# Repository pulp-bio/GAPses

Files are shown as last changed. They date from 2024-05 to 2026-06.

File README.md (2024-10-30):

# GAPses: 
## GAP9 based smart glasses for EEG and EOG acquisition and processing

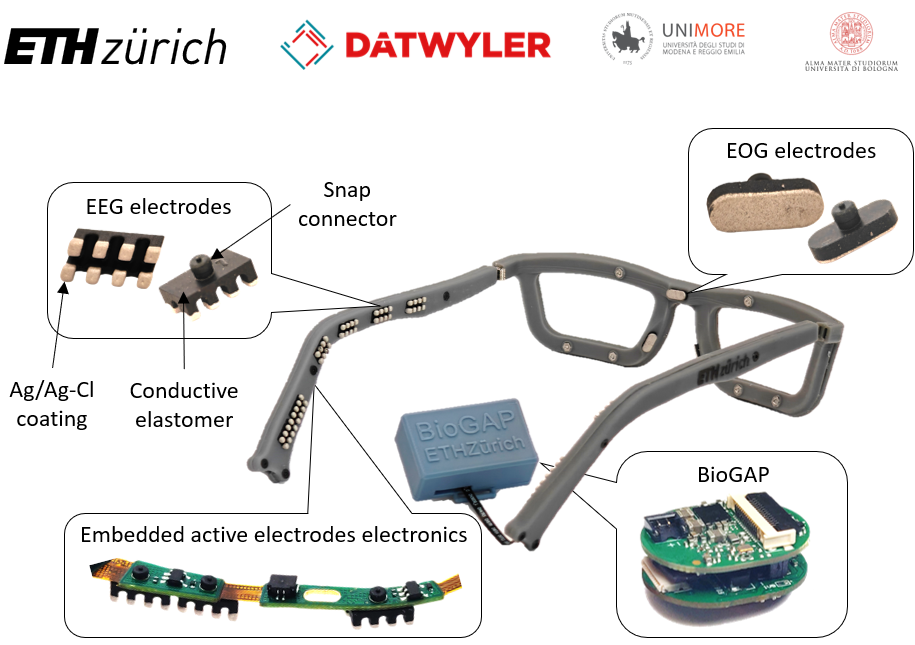
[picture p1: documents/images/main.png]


# Introduction

This repository contains the work in progress on the GAPses project.

GAPses are a pair of smart glasses for comfortable and fully dry acquisition and processing of EEG and EOG. The glasses are suitable for extended wear and various biopotential-based applications, including Human-Machine Interaction (HMI), biometric subject recognition, and real-time EEG/EOG analysis.

### Key Features
- **Lightweight & Comfortable**: The fully assembled glasses weigh only 40g and support unobtrusive, all-day wear.
- **Fully Dry Electrodes**: Custom soft electrodes provide stable contact without skin preparation.
- **Sleek Frame Design**: A sleek frame that discreetly houses electrodes and PCBs, ensuring a secure, comfortable fit for daily use.
- **Secure HMI Demonstration**: GAPses showcases a two-step Human-Machine Interaction (HMI) use case, where EEG-based biometric recognition (BrainMetrics) unlocks the device, followed by EOG-based HMI with a high information transfer rate.
- **End-to-End Edge Implementation**: The entire HMI use case, from BrainMetrics to EOG-based interactions, is processed on-device with GAP9’s ultra-low-power capabilities, enabling continuous, privacy-preserving operation on the edge.

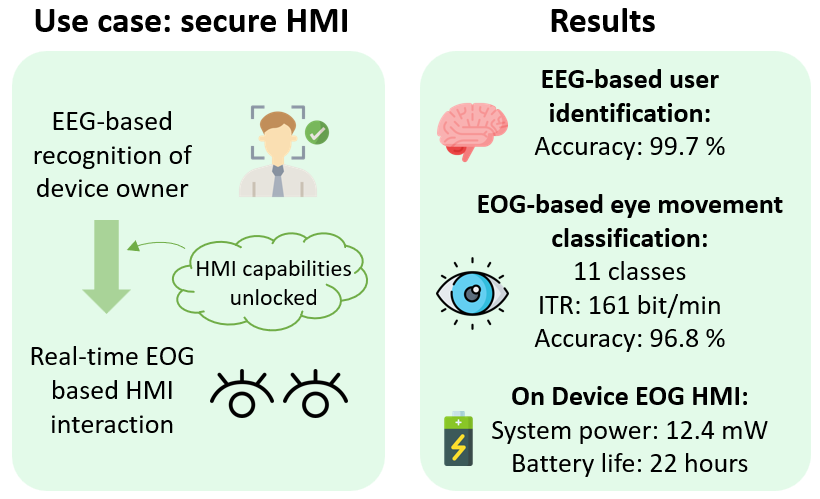
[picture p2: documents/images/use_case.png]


## System Diagram

The GAPses system comprises several key components:
- **BioGAP Acquisition and Processing Platform**: This platform enables real-time EEG and EOG data acquisition, processing, and classification on the edge with ultra-low power consumption using the GAP9 RISC-V processor.
- **Electrode Interface PCB**: A flex-rigid PCB embedded in the frame with active signal buffering stages and a direct PCB to electrode interface, reducing interference and artifacts.
- **Channel-Selection Interface PCB**: Allows users to switch between EEG-only and combined EEG-EOG configurations, optimizing channel selection for different use cases.

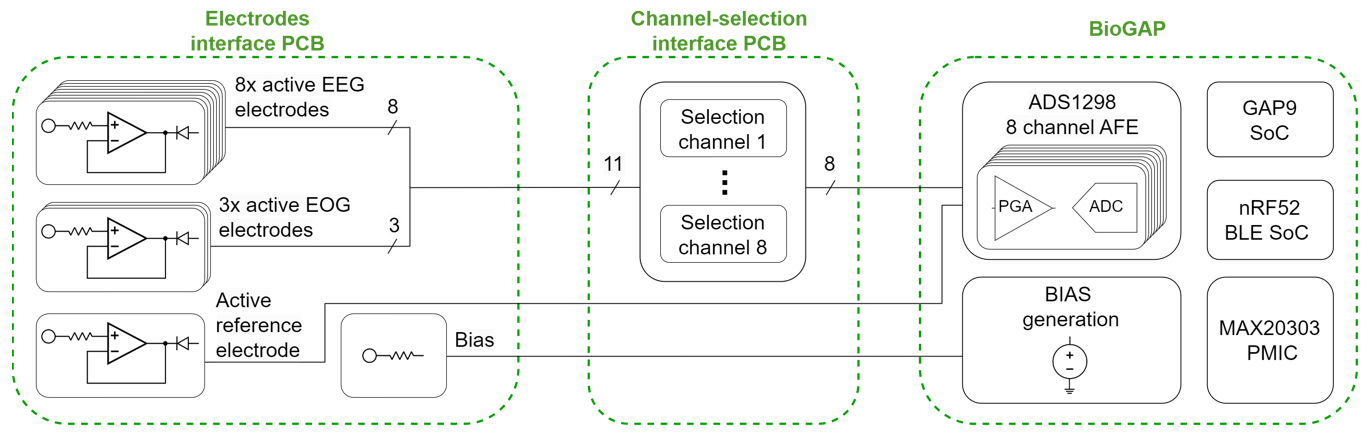
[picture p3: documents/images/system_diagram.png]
System Diagram


# Structure of the repository

This repository has the following folders:

- `hardware`, containing the Altium designer PCB source files and the frame design files 
    - Electrodes interface PCB (located at `hardware/PCBs/electrodes_interface_pcb`)
	- Breakout PCB (located at `hardware/PCBs/breakout_pcb`)
    - Frame files (located at `hardware/frame`)

- `documents`, containing the project documentation

# Citation
If you would like to reference the project, please cite the following paper:

```
@ARTICLE{frey2024gapses,
  author={Frey, Sebastian and Lucchini, Mattia Alberto and Kartsch, Victor and Ingolfsson, Thorir Mar and Bernardi, Andrea Helga and Segessenmann, Michael and Osieleniec, Jakub and Benatti, Simone and Benini, Luca and Cossettini, Andrea},
  journal={IEEE Transactions on Biomedical Circuits and Systems}, 
  title={GAPses: Versatile smart glasses for comfortable and fully-dry acquisition and parallel ultra-low-power processing of EEG and EOG}, 
  year={2024},
  volume={},
  number={},
  pages={1-11},
  keywords={Electroencephalography;Electrooculography;Electrodes;Glass;Smart glasses;Wireless communication;Biomedical monitoring;Wireless sensor networks;Sensors;Monitoring;BCI;EEG;embedded deployment;EOG;HMI;smart glasses;wearable devices},
  doi={10.1109/TBCAS.2024.3478798}}
```

# License

This project is open source. See the [LICENSE.README](./LICENSE.README.md) file for details.

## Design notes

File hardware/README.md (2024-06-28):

# Hardware files
This folder contains the following hardware design files:
 
- `PCBs`, containing the design files for the printed circuit boards (PCBs) of the GAPses project.
Each subdirectory corresponds to a separate PCB project. Inside you can find the Altium Nexus CAD design files and documentation in the `documents` folder.

- `frame`, containing the frame step files of the GAPses project.

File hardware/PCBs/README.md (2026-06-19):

# GAPses PCB design files
This directory contains the design files for selected printed circuit boards (PCBs) of the GAPses project.
Each subdirectory corresponds to a separate PCB project. Inside you can find the complete Altium Nexus CAD design files. To ease reproducability, gerber and NC drill files, schematics, bill of materials, assembly drawing and stackup regions are located in the `documents` folder of the respective PCB directory.

# License
The PCB design files are licensed under Solderpad v0.51 (`SHL-0.51`) license. Please, check the [hardware/PCBs/LICENSE](./LICENSE) file for details.

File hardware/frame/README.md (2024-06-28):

# GAPses frame design files

# License
The frame design files are licensed under the Solderpad v0.51 (`SHL-0.51`) license. Please, check the [hardware/frame/LICENSE](./LICENSE.md) file for details.

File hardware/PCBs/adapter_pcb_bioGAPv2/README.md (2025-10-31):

# BioGAP v2 Adapter PCB

The **BioGAP v2 Adapter PCB** facilitates the use of GAPses without the version 2 of the BioGAP acquisition platform.

## Features
- Enables the use of GAPses with BioGAP v2
- Supports EEG/EOG signal measurements

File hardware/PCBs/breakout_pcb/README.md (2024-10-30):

# Breakout PCB

The **Breakout PCB** facilitates the use of GAPses without the BioGAP acquisition platform. It provides access to all the signals on the electrode interface PCB, allowing other commercial or research biopotential acquisition platforms to be used in conjunction with GAPses.

## Features
- Enables the use of GAPses with non-BioGAP acquisition platforms
- Provides direct access to all electrode interface signals
- Supports EEG/EOG signal measurements
- Includes a DC offset of 2.048 V for proper operation of embedded electronics

## How to Connect the Breakout PCB

Follow these steps to connect the breakout PCB to your measurement system:

### 1. Powering the Breakout PCB
To power the breakout PCB, follow these steps:
   - Connect **GND** and **AVDD** to a lab power supply.
   - Set the power supply voltage to **3.0V (AVDD)**.

### 2. Measuring EEG/EOG Signals
Once powered, you can measure EEG and EOG signals by following these guidelines:
   - The signals are measured with respect to the **REF** pin (e.g., TL1 - REF, TL2 - REF, EOG L - REF, etc.).
   - The signals will have a **DC offset of 2.048 V**, which can be measured on the **BIAS** pin. This offset is necessary for the proper operation of the embedded electronics in the glasses frame and is generated by the breakout PCB.

### 3. Connecting to Measurement Device
   - Connect the channels you wish to measure to your measurement device. Ensure that the signals are correctly referenced with respect to the **REF** pin.

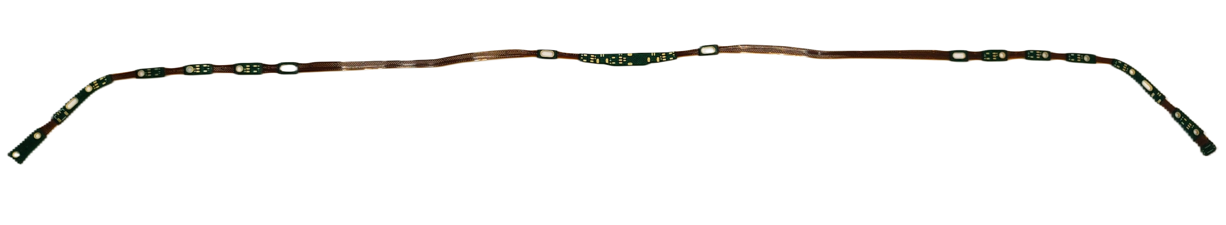
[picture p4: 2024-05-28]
documents/images/electrodes_interface_pcb.png

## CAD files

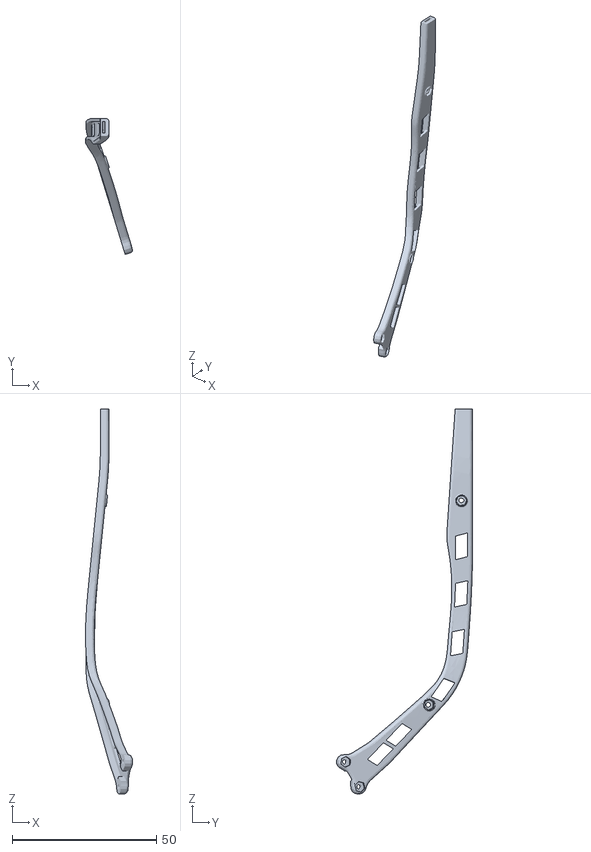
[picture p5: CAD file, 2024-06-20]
hardware/frame/ARM_RIGHT.stl
16.3 x 47.1 x 133.6

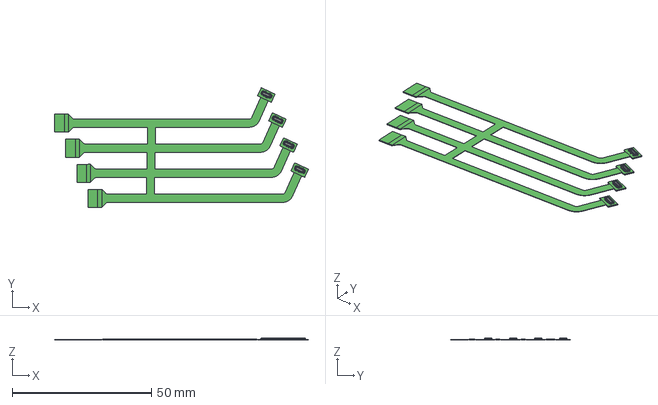
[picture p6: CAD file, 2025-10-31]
hardware/PCBs/adapter_pcb_bioGAPv2/flex_interface.step
91.3 x 43.0 x 0.845 mm

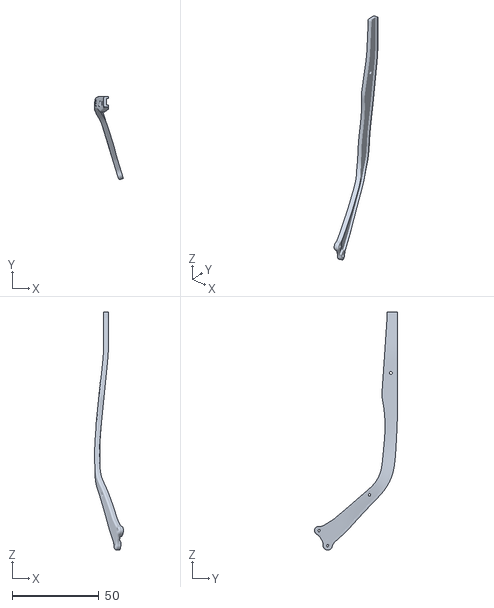
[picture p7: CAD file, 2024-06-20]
hardware/frame/LID_ETH.stl
16.6 x 47.8 x 137.1

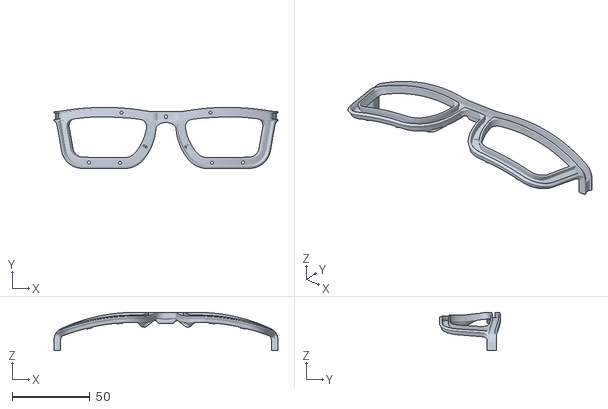
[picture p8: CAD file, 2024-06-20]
hardware/frame/FRONT_FRAME.stl
144.4 x 39.4 x 24.8

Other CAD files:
hardware/frame/ARM_LEFT.stl
hardware/frame/LID_Datwyler.stl

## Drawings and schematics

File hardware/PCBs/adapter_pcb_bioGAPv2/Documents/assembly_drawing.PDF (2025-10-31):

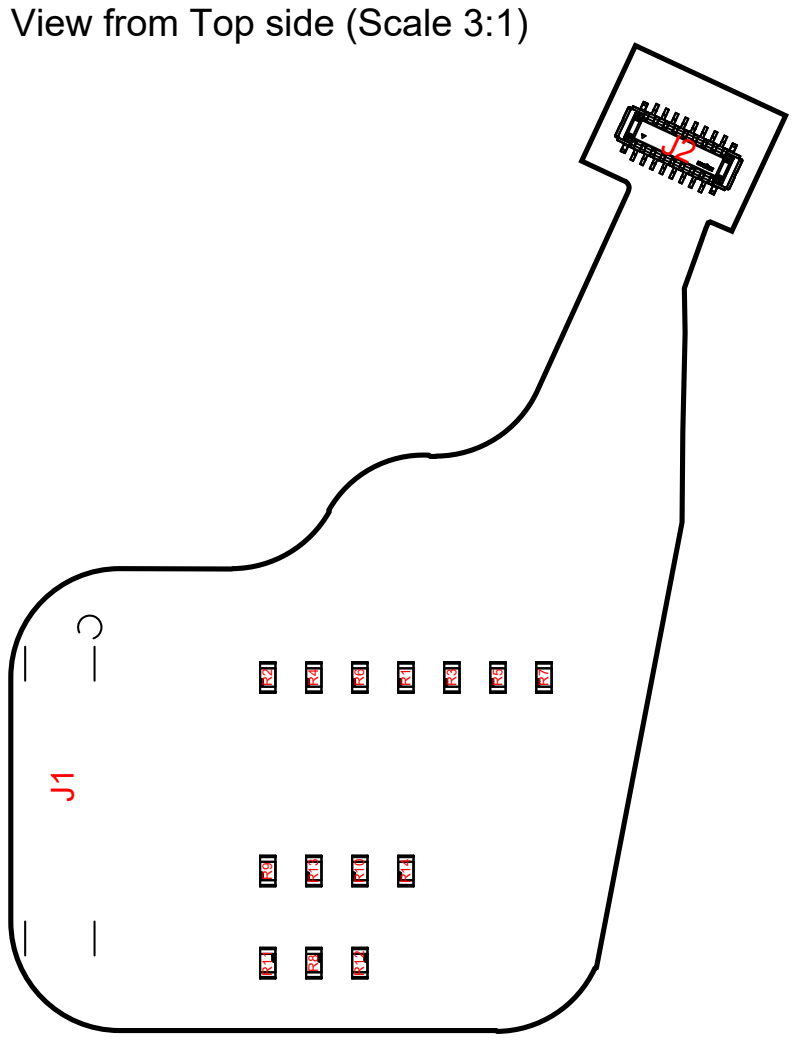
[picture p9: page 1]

View from Top side (Scale 3:1)

Drawing number:
Date:
C:\Users\s-fre\Github\GAPses\hardware\PCBs\adapter_pcb_bioGAPv2\ASSEMBLY.PCBDwf
File:

Laboratory: IIS ETH Zürich
Drawn by:

ASSEMBLY.PCBDwf
Sheet:
Page =sheetnumber of =sheettotal

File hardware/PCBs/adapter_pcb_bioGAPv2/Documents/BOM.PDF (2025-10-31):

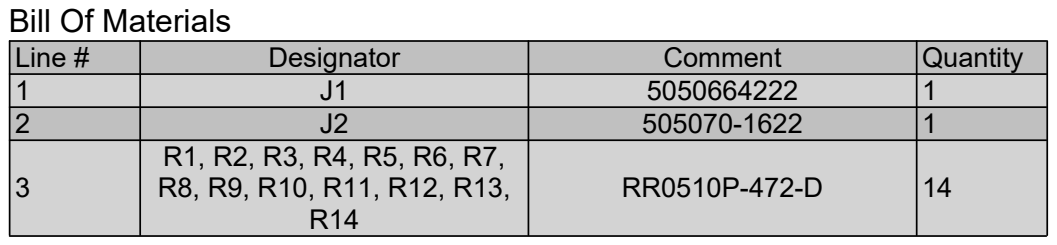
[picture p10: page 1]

Line # | Designator | Comment | Quantity
1 | J1 | 5050664222 | 1
2 | J2 | 505070-1622 | 1
3 | R1, R2, R3, R4, R5, R6, R7, R8, R9, R10, R11, R12, R13, R14 | RR0510P-472-D | 14

Project:

Drawing number: Rev: v1.0 Date: 07.07.2025 19:31 | Format: | Laboratory: IIS ETH Zürich Drawn by: S.Frey | Sheet: BOM.PCBDwf Page =sheetnumber of =sheettotal

C:\Users\s-fre\Github\GAPses\hardware\PCBs\adapter_pcb_bioGAPv2\BOM.PCBDwf

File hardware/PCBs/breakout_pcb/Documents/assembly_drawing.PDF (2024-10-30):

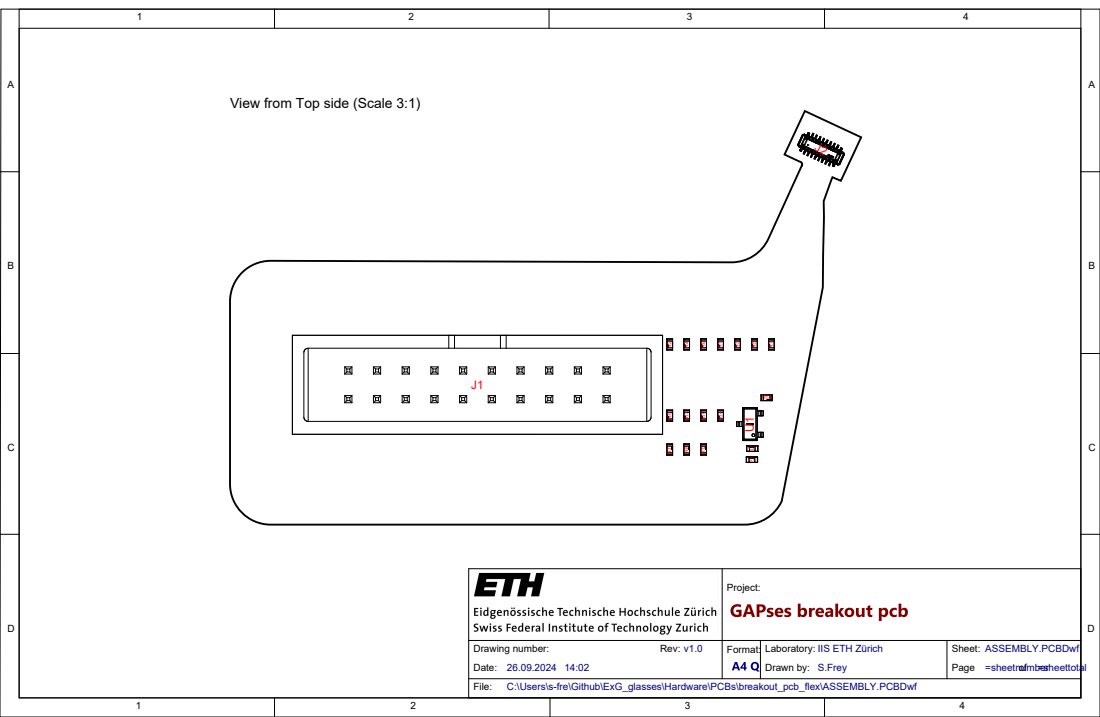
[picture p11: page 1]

View from Top side (Scale 3:1)

Laboratory: IIS ETH Zürich
Drawn by:

Sheet:
ASSEMBLY.PCBDwf
Page =sheetnumber of =sheettotal

C:\Users\s-fre\Github\ExG_glasses\Hardware\PCBs\breakout_pcb_flex\ASSEMBLY.PCBDwf

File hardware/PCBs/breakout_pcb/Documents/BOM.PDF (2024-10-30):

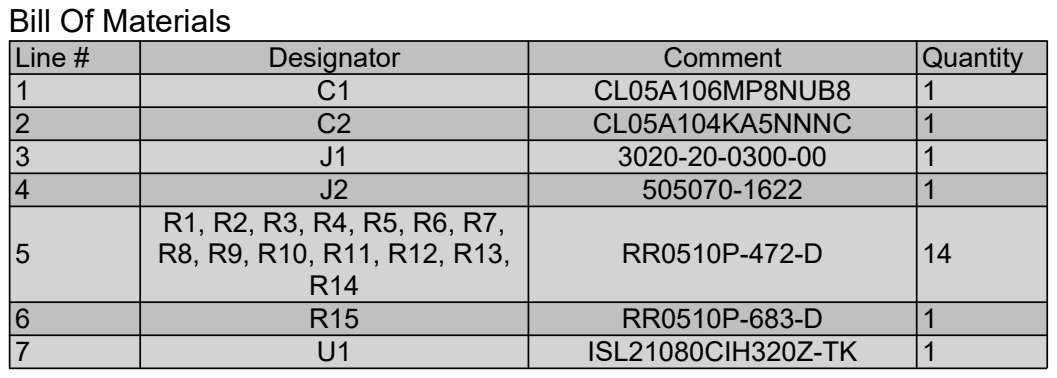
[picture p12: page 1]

Line # | Designator | Comment | Quantity
1 | C1 | CL05A106MP8NUB8 | 1
2 | C2 | CL05A104KA5NNNC | 1
3 | J1 | 3020-20-0300-00 | 1
4 | J2 | 505070-1622 | 1
5 | R1, R2, R3, R4, R5, R6, R7, R8, R9, R10, R11, R12, R13, R14 | RR0510P-472-D | 14

6 | R15 | RR0510P-683-D | 1
7 | U1 | ISL21080CIH320Z-TK | 1

Project:

Drawing number: Rev: v1.0 Date: 26.09.2024 13:59 | Format: | Laboratory: IIS ETH Zürich Drawn by: S.Frey | Sheet: BOM.PCBDwf Page =sheetnumber of =sheettotal

C:\Users\s-fre\Github\ExG_glasses\Hardware\PCBs\breakout_pcb_flex\BOM.PCBDwf

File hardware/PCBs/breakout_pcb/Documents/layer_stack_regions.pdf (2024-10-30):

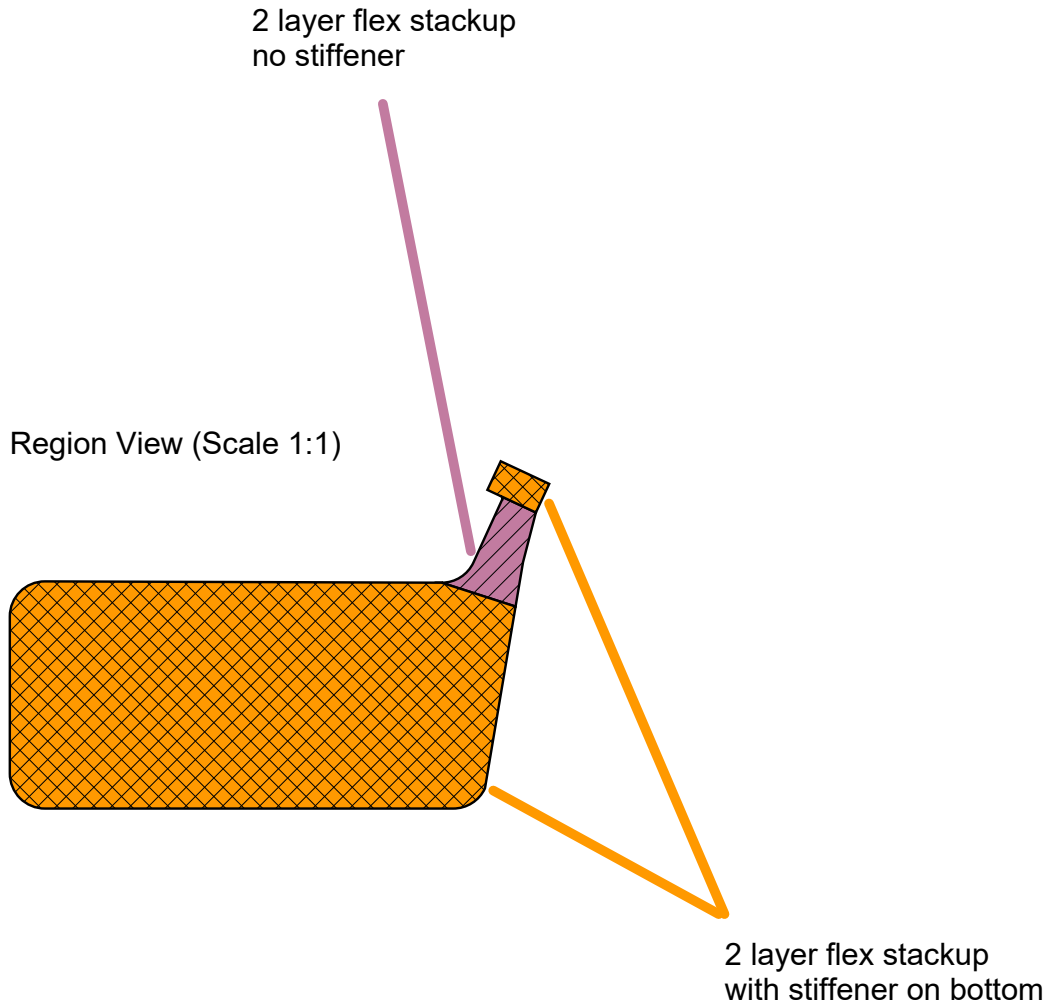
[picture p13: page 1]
File:

2 layer flex stackup
no stiffener

Region View (Scale 1:1)

with stiffener on bottom

Project:

Drawing number: Rev: v1.0 Date: 03.07.2024 23:51 | Format: | Laboratory: IIS ETH Zürich Drawn by: S.Frey | Sheet: STACKUP.PCBDwf Page =sheetnumber of =sheettotal

C:\Users\s-fre\Github\ExG_glasses\Hardware\PCBs\breakout_pcb_flex\STACKUP.PCBDwf

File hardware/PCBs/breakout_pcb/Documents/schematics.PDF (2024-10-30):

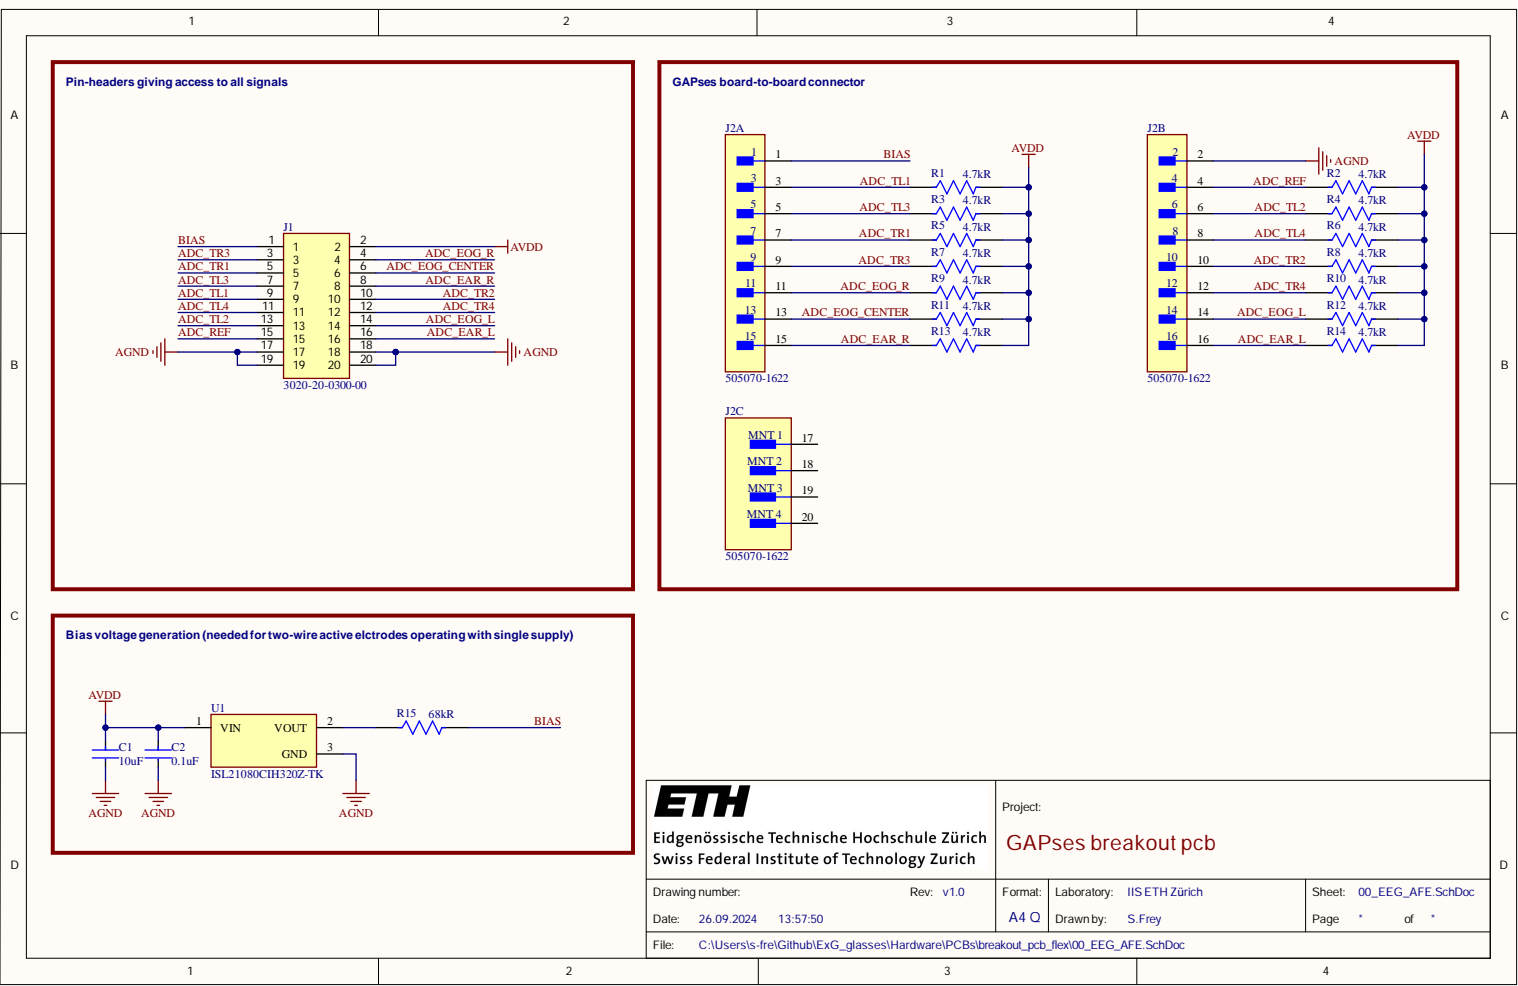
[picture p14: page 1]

Bias voltage generation (needed fortwo-wire active elctrodes operating with single supply)

C:\Users\s-fre\Github\ExG_glasses\Hardware\PCBs\breakout_pcb_flex\00_EEG_AFE.SchDoc

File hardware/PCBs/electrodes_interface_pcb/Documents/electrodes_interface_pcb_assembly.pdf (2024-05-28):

A

B

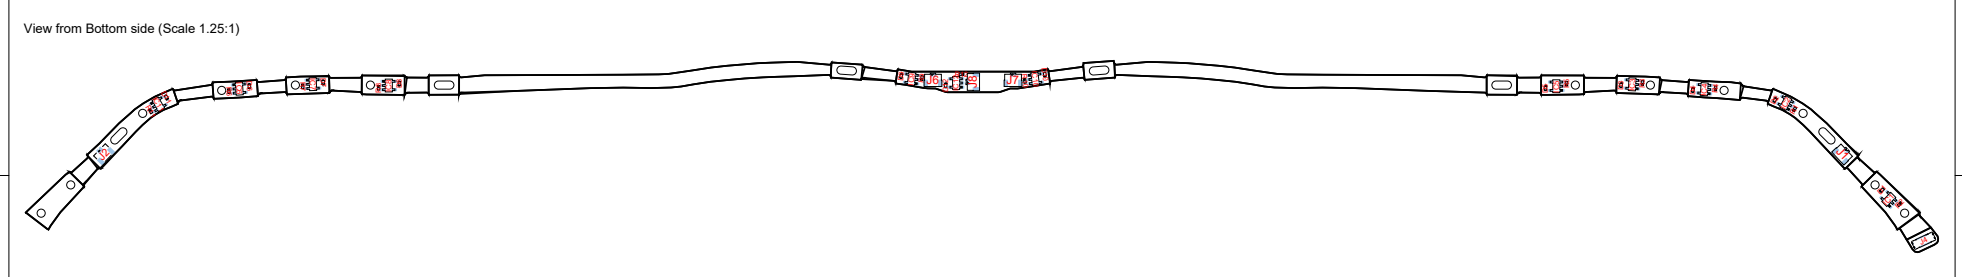
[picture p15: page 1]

View from Bottom side (Scale 1.25:1)

Drawing title:

Drawing number: Rev: v1.0 Date: 15.05.2024 15:54 | Format: | Laboratory:Integrated Systems Lab Drawn by: Sebastian Frey | Project: assembly.PCBDwf

File:
C:\Users\s-fre\Github\GAPses\Hardware\PCBs\electrodes_interface_pcb\assembly.PCBDwf

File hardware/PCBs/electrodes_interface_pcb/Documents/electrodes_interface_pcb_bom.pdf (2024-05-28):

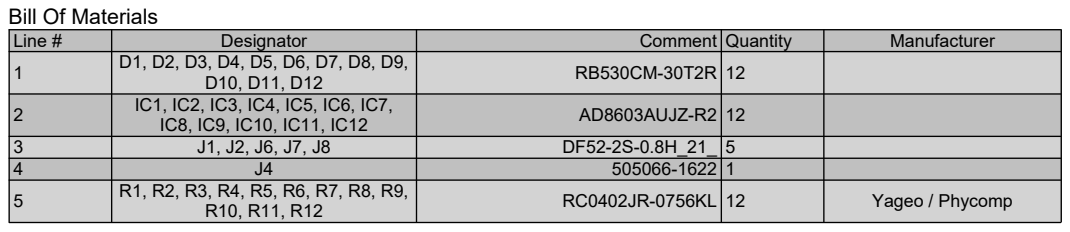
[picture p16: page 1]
File:

Bill Of Materials

Line # | Designator | Comment | Quantity | Manufacturer
1 | D1, D2, D3, D4, D5, D6, D7, D8, D9, D10, D11, D12 | RB530CM-30T2R | 12

2 | IC1, IC2, IC3, IC4, IC5, IC6, IC7, IC8, IC9, IC10, IC11, IC12 | AD8603AUJZ-R2 | 12

3 | J1, J2, J6, J7, J8 | DF52-2S-0.8H_21_ | 5
4 | J4 | 505066-1622 | 1
5 | R1, R2, R3, R4, R5, R6, R7, R8, R9, R10, R11, R12 | RC0402JR-0756KL | 12 | Yageo / Phycomp

Project:

Drawing number: Rev: v1.0 Date: 15.05.2024 15:54 | Format: | Laboratory: Integrated Systems Lab Drawn by: Sebastian Frey | Sheet: bom.PCBDwf

C:\Users\s-fre\Github\GAPses\Hardware\PCBs\electrodes_interface_pcb\bom.PCBDwf

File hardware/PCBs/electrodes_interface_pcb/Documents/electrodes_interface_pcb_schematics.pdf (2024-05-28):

ADC_REF Signal Input | PCB - active electrodes
ADC_TL1 Signal Input | PCB - active electrodes

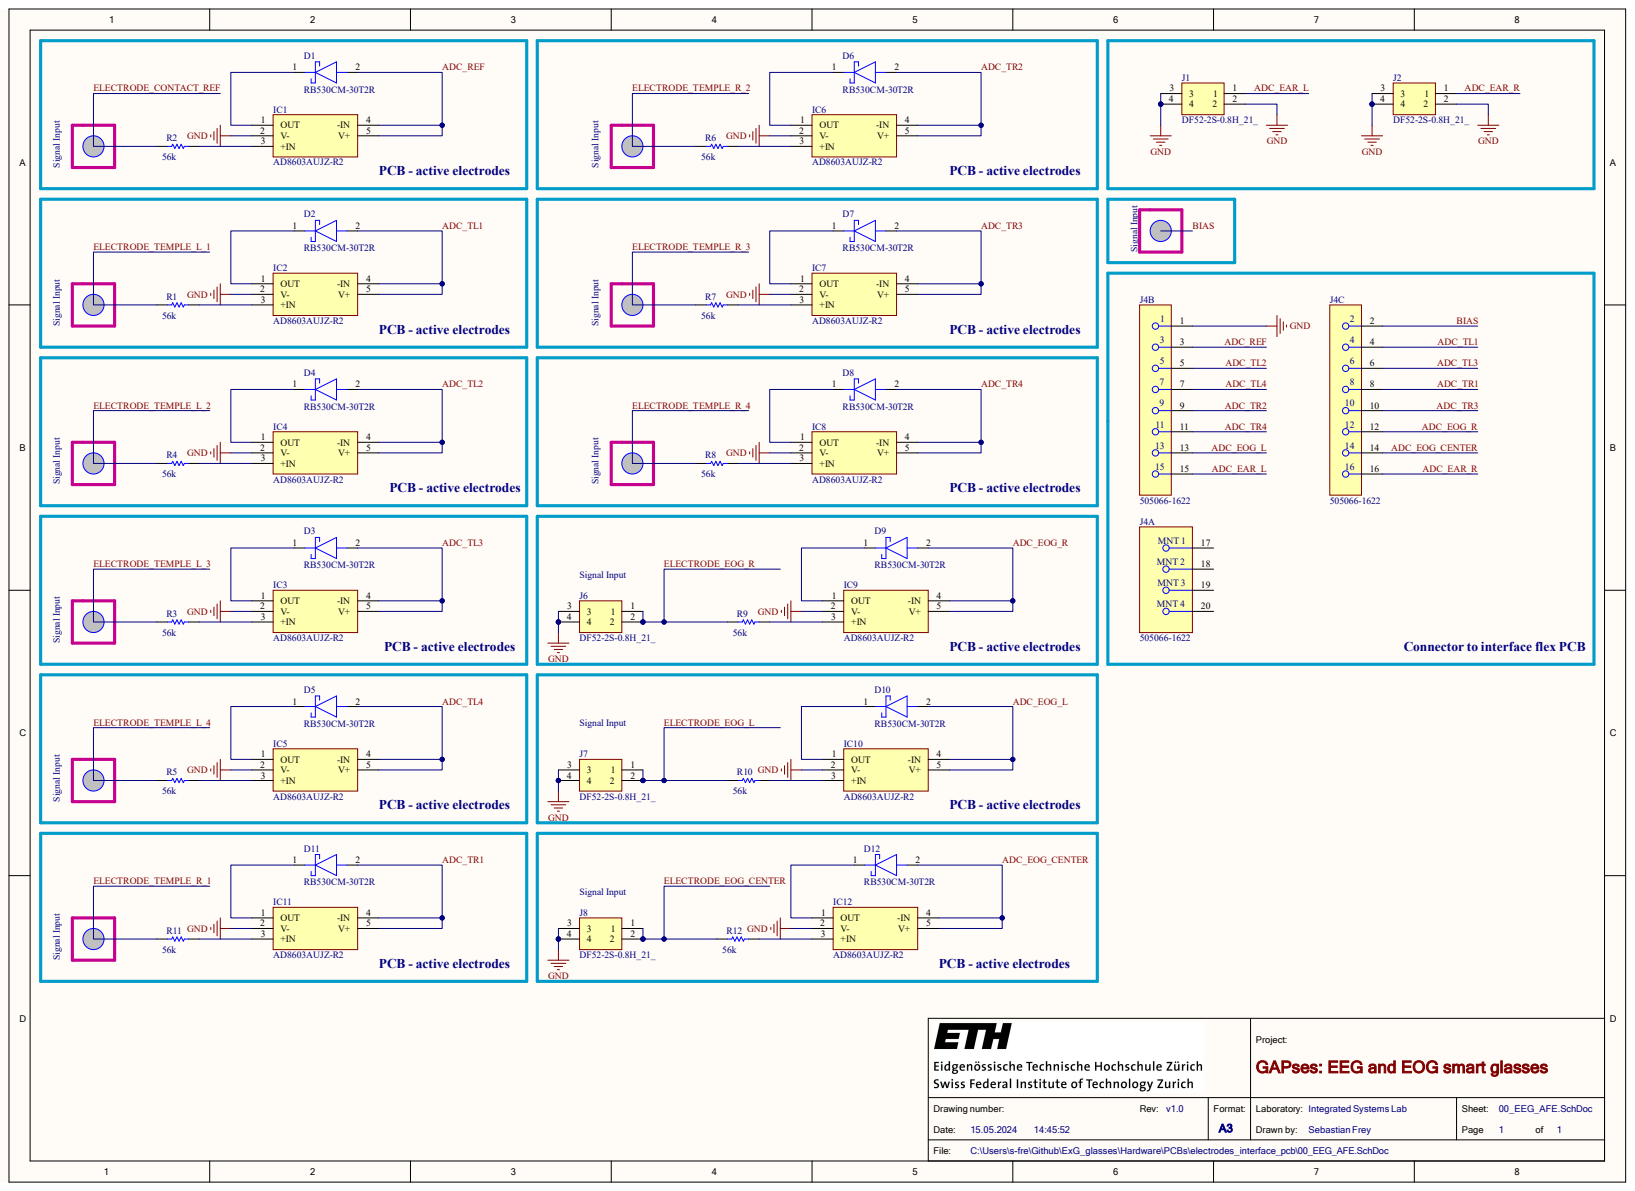
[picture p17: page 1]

Connector to interface flex PCB

Project: GAPses: EEG and EOG smart glasses

Drawing number: Rev: v1.0 Date: 15.05.2024 14:45:52 | Format: A3 | Laboratory: Integrated Systems Lab Drawn by: Sebastian Frey | Sheet: 00_EEG_AFE.SchDoc Page of 1 1

C:\Users\s-fre\Github\ExG_glasses\Hardware\PCBs\electrodes_interface_pcb\00_EEG_AFE.SchDoc

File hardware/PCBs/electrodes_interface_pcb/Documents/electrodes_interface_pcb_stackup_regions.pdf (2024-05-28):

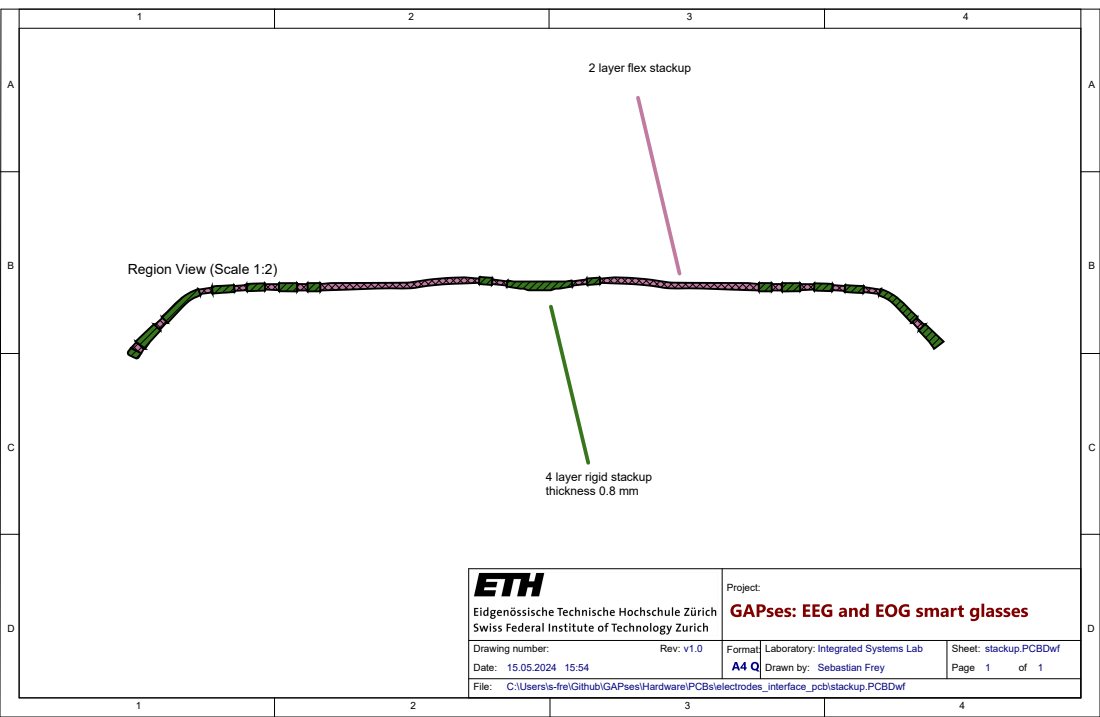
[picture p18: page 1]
File:

2 layer flex stackup

Region View (Scale 1:2)

4 layer rigid stackup
thickness 0.8 mm

Project:

Drawing number: Rev: v1.0 Date: 15.05.2024 15:54 | Format: | Laboratory: Integrated Systems Lab Drawn by: Sebastian Frey | Sheet: stackup.PCBDwf

C:\Users\s-fre\Github\GAPses\Hardware\PCBs\electrodes_interface_pcb\stackup.PCBDwf

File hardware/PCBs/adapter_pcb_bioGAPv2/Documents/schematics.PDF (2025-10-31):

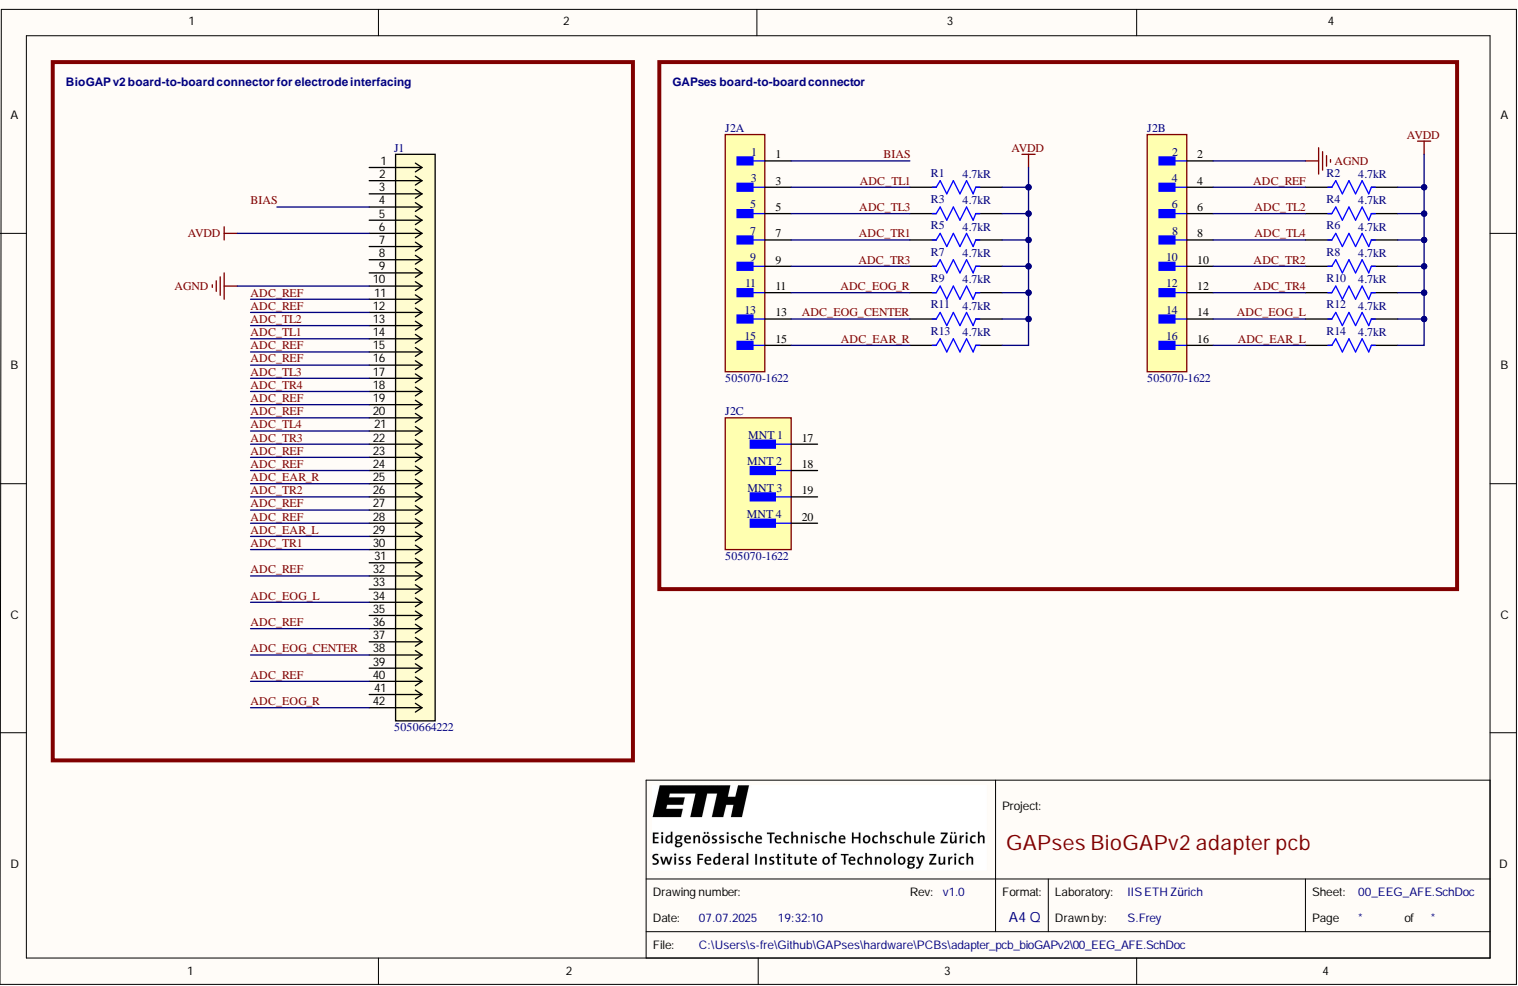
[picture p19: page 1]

Proje ct: G A P s e s B i o G A P v 2 a d a p te r p c b

Drawing num be r: R ev : v 1 . 0 D a te : 07.07. 2025 19:32: 1 0 | Forma t: A 4 Q | Laboratory : I IS ET H Z üric h Drawn by : S. F rey | Shee t: 00_EEG_AF E . S ch D oc Pag e * of *

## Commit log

2024-05-30 Create structure to upload frame design files
2024-06-20 Add files via upload
    Upload of frame files.
    [ARM_LEFT.stl, ARM_RIGHT.stl, FRONT_FRAME.stl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]
2024-09-26 Add PCB files for breakout PCB
    [00_EEG_AFE.SchDoc, GAPses_breakout_pcb.PrjPcb, breakout_pcb.PcbDoc]
2025-07-07 Add BioGAPv2 adapter PCB
    [00_EEG_AFE.SchDoc, adapter_pcb_bioGAPv2.PcbDoc, adapter_pcb_bioGAPv2.PrjPcb]
2025-10-31 add step file
    [flex_interface.step]
